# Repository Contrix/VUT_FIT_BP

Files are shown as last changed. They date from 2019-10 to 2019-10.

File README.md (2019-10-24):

# Bakalářská práce
### Vestavěný systém pro monitorování výšky vodní hladiny

Autor práce: Jiří Hanák\
Ak. rok: 2018/2019\
Vedoucí: Ing. Václav Šimek\
Oponent: Ing. Tomáš Kašpárek\
Publikace na webu školy: https://www.vutbr.cz/studenti/zav-prace/detail/122051

##### Abstrakt 
Tato práce se zabývá návrhem a realizací vestavěného systému pro monitorování výšky vodní hladiny. Účelem systému je řízení napouštění nádrže na základě výšky vodní hladiny. V první řadě je věnována pozornost přehledu stávajících měřicích technik a výběru vhodných měřicích prvků pro daný scénář. Vestavěný systém staví na bezkontaktních snímačích TFmini a JSN-SR04T-2.0. Řízení systému obstarává mikrokontrolér řady STM32F0 od firmy STMicroelectronics programovaný v jazyce C s využitím abstraktní vrstvy HAL. Naměřené výsledky jsou odesílány přes Wi-Fi SoC ESP8266EX na demonstrační server v jazyce Python.

##### Klíčová slova
Vestavěný systém, měření vzdálenosti, STM32, návrh DPS, nádrž, voda, ESP8266, ČSN EN 60 529, HAL

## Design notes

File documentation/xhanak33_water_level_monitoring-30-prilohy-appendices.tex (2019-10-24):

\chapter{Finální podoba vestavěného systému}
    \label{sec:fotky}

    \begin{figure*}[h]
        \centering
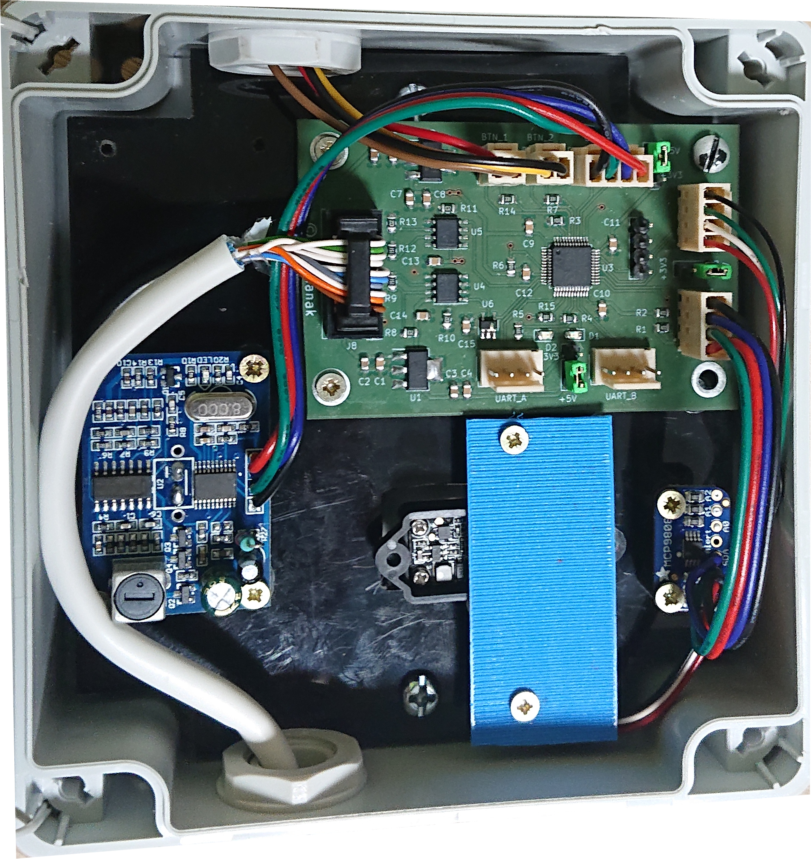
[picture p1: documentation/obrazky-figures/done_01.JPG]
        
        \caption{Pohled na otevřenou krabici reprezentující řídicí část vestavěného systému.}
    \end{figure*}

    \begin{figure*}[h]
        \centering
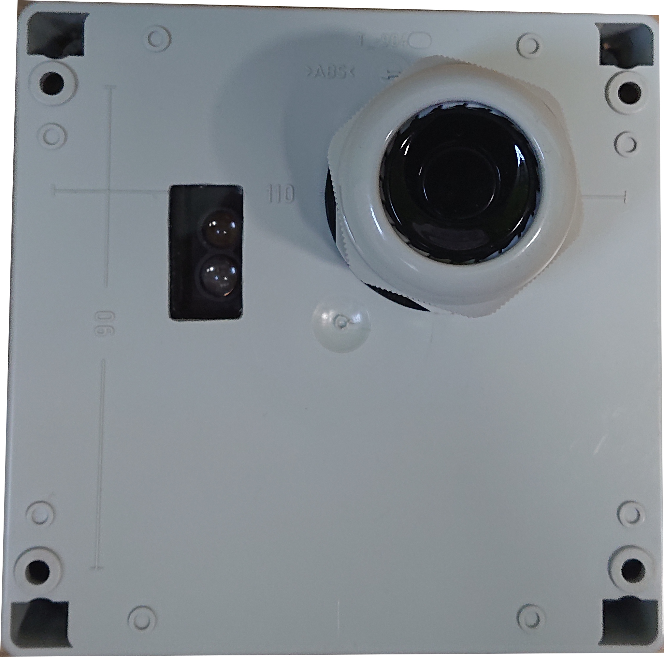
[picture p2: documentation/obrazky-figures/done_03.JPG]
        
        \caption{Pohled na spodní část krabice reprezentující řídicí část vestavěného systému.}
    \end{figure*}

    \begin{figure*}[h]
        \centering
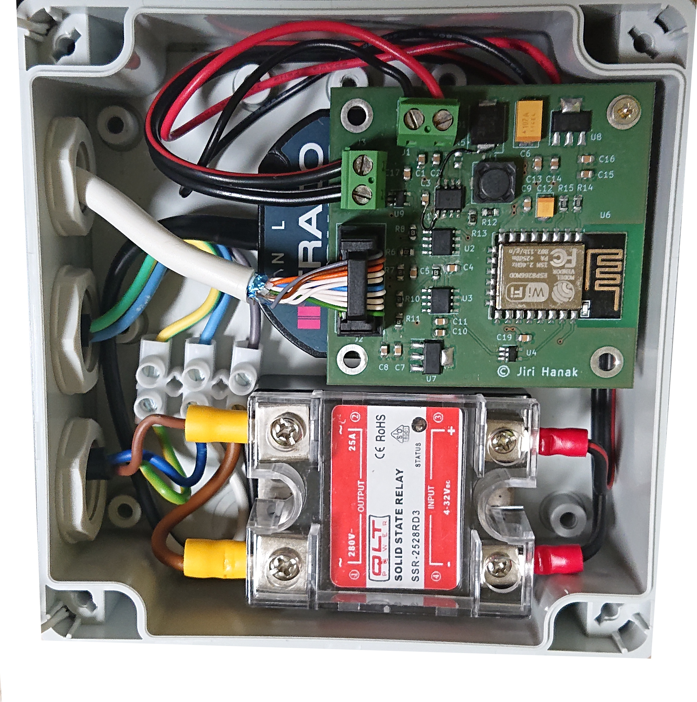
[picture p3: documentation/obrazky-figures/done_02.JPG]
        
        \caption{Pohled na otevřenou krabici reprezentující podpůrnou část vestavěného systému.}
    \end{figure*}
\chapter{Výsledky testovacího měření TFmini a JSN-SR04T-2.0}
	\label{sec:values}
	\begin{table*}[h]\centering
        \begin{tabular}{@{}cccccccc@{}}
            \toprule
            \multirow{2}{*}{\textbf{Reference}} & \multicolumn{3}{c}{\textbf{TFmini}} && \multicolumn{3}{c}{\textbf{JSN-SR04T-2.0}}\\ 
            \cmidrule{2-4}\cmidrule{6-8}
            	& \textbf{Podlaha}    & \textbf{Voda}      & \textbf{Pěna}&& \textbf{Podlaha}    & \textbf{Voda}      & \textbf{Pěna}\\
            \midrule
            400		& 372	& 988	& 470	&& 398	& 353	& 357	\\ 
            500		& 486	& 1040	& 589	&& 506	& 448	& 452	\\ 
            600		& 590	& 1087	& 673	&& 601	& 558	& 558	\\ 
            700		& 680	& 1142	& 744	&& 691	& 644	& 665	\\ 
            800		& 782	& 1155	& 816	&& 795	& 750	& 756	\\ 
            900		& 872	& 1169	& 905	&& 896	& 853	& 853	\\ 
            1000	& 995	& 1212	& 1009	&& 1002	& 941	& 982	\\ 
            1100	& 1092	& 1240	& 1087	&& 1096	& 1047	& 1073	\\
            1200	& 1185	& 1255	& 1182	&& 1198	& 1183	& 1157	\\ 
            1300	& 1280	& 1321	& 1275	&& 1301	& 1247	& 1252	\\ 
            1400	& 1381	& 1408	& 1379	&& 1394	& 1355	& 1370	\\ 
            1500	& 1486	& 1511	& 1462	&& 1487	& 1459	& 1510	\\ 
            1600	& 1584	& 1631	& 1547	&& 1590	& 1592	& 1558	\\ 
            1700	& 1672	& 1718	& 1657	&& 1693	& 1655	& 1663	\\ 
            1800	& 1786	& 1790	& 1750	&& 1792	& 1741	& 1754	\\ 
            1900	& 1875	& 1899	& 1878	&& 1900	& 1853	& 1853	\\ 
            2000	& 1995	& 1998	& 1953	&& 1989	& 1976	& 1948	\\ 
            \bottomrule
        \end{tabular}
        \caption{V~tabulce jsou uvedeny změřené hodnoty optickým snímačem \io{TFmini} a ultrazvukovým snímačem \io{JSN-SR04T-2.0} kolmo proti podlaze, klidné vodní hladině a zpěněné hladině vody při teplotě $20\unit{^\circ C}$. Všechny hodnoty jsou uvedeny v~milimetrech.}
    \end{table*}

\chapter{Ukázka konfiguračního souboru}
	\label{sec:cfg}
	\begin{lstlisting}
    # datum zmeny pro 23.3. 2018, verze 2
CHANGE_ID=2018032302
    # pocet minut do opetovneho nacteni konfigurace a odeslani namerenych dat
REFRESH=1440
    # adresa severu
SERVER="muj_server.cz/"
    # umisteni obsluzneho skriptu na serveru
LOCATION="water_level_monitoring"
    # port skriptu
PORT=5000
    # wifi sit 
SSID="moje_sit"
    # heslo na wifi
PASSWORD="heslo_na_wifi"
    # vyska nadrze v milimetrech
HEIGHT=2000
    # maximalni vyska hladiny v milimetrech
MAXUMUM=1800
    # minimalni vyska hladiny v milimetrech
MINIMUM=50
    # ovladani cerpadla v rezimu napousteni
PUMP_ACTIVE=1
    # pocet mereni na vyhodnoceni vysky vodni hladiny
AVERAGE_COUNT=5
    # soucet identifikatoru aktivnich senzoru
CONTROL_SENSORS=15\end{lstlisting}

\chapter{Ukázka konfigurace přes rozhraní UART}
    \label{sec:cfg}
    \begin{lstlisting}
Odposlech
cu -l /dev/ttyUSB0 -s 9600

Zapis
Inicializace
echo -ne '5000\r\n' > /dev/ttyUSB0
echo -ne '"10.42.0.1"\r\n' > /dev/ttyUSB0

Zmena konfigurace
echo -ne '\x07' > /dev/ttyUSB0
echo -ne 'REFRESH=1\r\n' > /dev/ttyUSB0
echo -ne 'SERVER="10.42.0.1"\r\n' > /dev/ttyUSB0
echo -ne 'LOCATION="water_level_mnt"\r\n' > /dev/ttyUSB0
echo -ne '\x06' > /dev/ttyUSB0

Programovani
STM32_Programmer_CLI -c port=SWD reset=HWrst -w main.bin 0x08000000 -v -rst

Uplna ukazkova inicializace
echo -ne '1\r\n' > /dev/ttyUSB0
echo -ne '"10.42.0.1"\r\n' > /dev/ttyUSB0
echo -ne '"water_level_monitoring"\r\n' > /dev/ttyUSB0
echo -ne '5000\r\n' > /dev/ttyUSB0
echo -ne '"Wifi"\r\n' > /dev/ttyUSB0
echo -ne '"heslo"\r\n' > /dev/ttyUSB0
echo -ne '5000\r\n' > /dev/ttyUSB0
echo -ne '2000\r\n' > /dev/ttyUSB0
echo -ne '200\r\n' > /dev/ttyUSB0
echo -ne '1\r\n' > /dev/ttyUSB0
echo -ne '3\r\n' > /dev/ttyUSB0
echo -ne '15\r\n' > /dev/ttyUSB0\end{lstlisting}

\chapter{Schéma řídicí desky}
	\label{sec:main_board_scheme}
	\includepdf[landscape=true, offset=20 -40]{obrazky-figures/main_board_scheme.pdf}

\chapter{Plošný spoj pro řídicí desku}
	\label{sec:main_board_pcb}
    \includepdf[pages={1,2}, landscape=true, angle=270, offset=20 -40]{obrazky-figures/main_board_pcb.pdf}

\chapter{Schéma podpůrné desky}
	\label{sec:support_board_scheme}
	\includepdf[landscape=true, offset=20 -40]{obrazky-figures/support_board_scheme.pdf}

\chapter{Plošný spoj pro podpůrnou desku}
	\label{sec:support_board_pcb}
	\includepdf[pages={1,2}, landscape=true, offset=20 -40]{obrazky-figures/support_board_pcb.pdf}

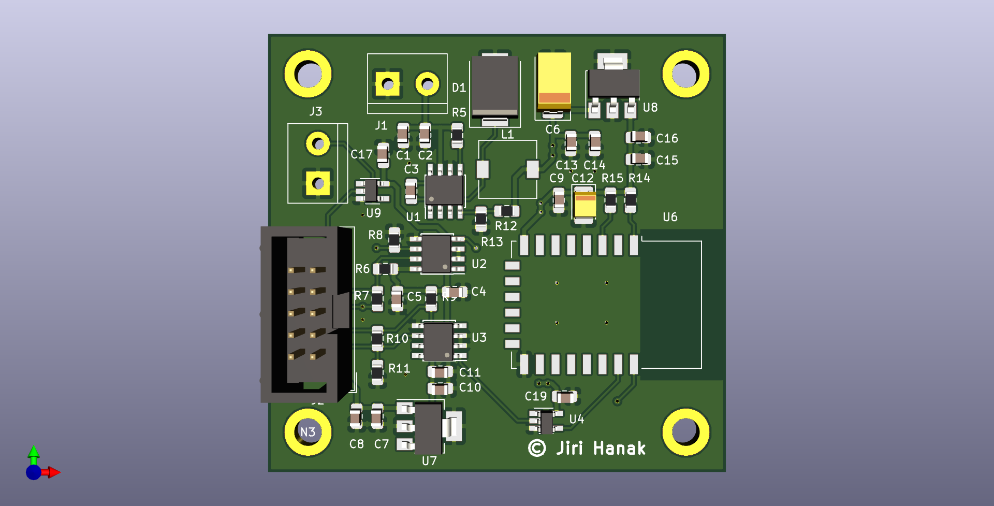
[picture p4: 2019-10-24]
documentation/obrazky-figures/support_board_3D.png

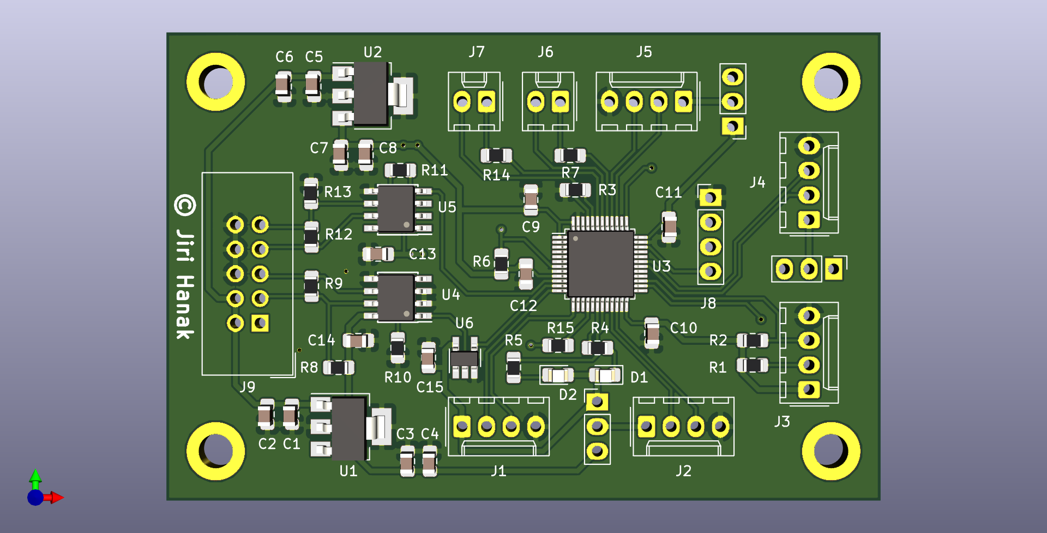
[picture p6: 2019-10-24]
documentation/obrazky-figures/main_board_3D.png

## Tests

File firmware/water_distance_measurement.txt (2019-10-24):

Configuration	water_distance_measurement
STM32CubeMX 	4.27.0
Date	05/14/2019
MCU	STM32F030CCTx

PERIPHERALS	MODES	FUNCTIONS	PINS
I2C2	I2C	I2C2_SCL	PB13
I2C2	I2C	I2C2_SDA	PB14
SYS	Serial_Wire	SYS_SWCLK	PA14
SYS	Serial_Wire	SYS_SWDIO	PA13
SYS	SysTick	SYS_VS_Systick	VP_SYS_VS_Systick
USART1	Asynchronous	USART1_RX	PA10
USART1	Asynchronous	USART1_TX	PA9
USART2	Asynchronous	USART2_RX	PA3
USART2	Asynchronous	USART2_TX	PA2
USART3	Asynchronous	USART3_RX	PB11
USART3	Asynchronous	USART3_TX	PB10
USART4	Asynchronous	USART4_RX	PA1
USART4	Asynchronous	USART4_TX	PA0
USART5	Asynchronous	USART5_RX	PB4
USART5	Asynchronous	USART5_TX	PB3

Pin Nb	PINs	FUNCTIONs	LABELs
10	PA0	USART4_TX	
11	PA1	USART4_RX	
12	PA2	USART2_TX	
13	PA3	USART2_RX	
16	PA6	GPIO_Output	SSR
18	PB0	GPIO_Output	LED1
19	PB1	GPIO_Output	LED2
21	PB10	USART3_TX	
22	PB11	USART3_RX	
26	PB13	I2C2_SCL	
27	PB14	I2C2_SDA	
30	PA9	USART1_TX	
31	PA10	USART1_RX	
34	PA13	SYS_SWDIO	
37	PA14	SYS_SWCLK	
39	PB3	USART5_TX	
40	PB4	USART5_RX	
41	PB5	GPIO_Output	Matrix_X1
42	PB6	GPIO_Input	Matrix_Y1
43	PB7	GPIO_Output	Matrix_X2
45	PB8	GPIO_Input	Matrix_Y2

SOFTWARE PROJECT

Project Settings : 
Project Name : water_distance_measurement
Project Folder : /mnt/sda6/fit/bp/bachelors_thesis/firmware
Toolchain / IDE : Makefile
Firmware Package Name and Version : STM32Cube FW_F0 V1.9.0

Code Generation Settings : 
STM32Cube Firmware Library Package : Copy all used libraries into the project folder
Generate peripheral initialization as a pair of '.c/.h' files per peripheral : No
Backup previously generated files when re-generating : No
Delete previously generated files when not re-generated : Yes
Set all free pins as analog (to optimize the power consumption) : Yes

Toolchains Settings : 
Compiler Optimizations :

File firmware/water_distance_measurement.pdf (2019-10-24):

## water_distance_measurement Project Configuration Report

# 1. Description

## 1.1. Project

Project Name | water_distance_measurement
Board Name | custom
Generated with: | STM32CubeMX 4.27.0
Date | 05/14/2019

## 1.2. MCU

MCU Series | STM32F0
MCU Line | STM32F0x0 Value Line
MCU name | STM32F030CCTx
MCU Package | LQFP48
MCU Pin number | 48

# 2. Pinout Configuration

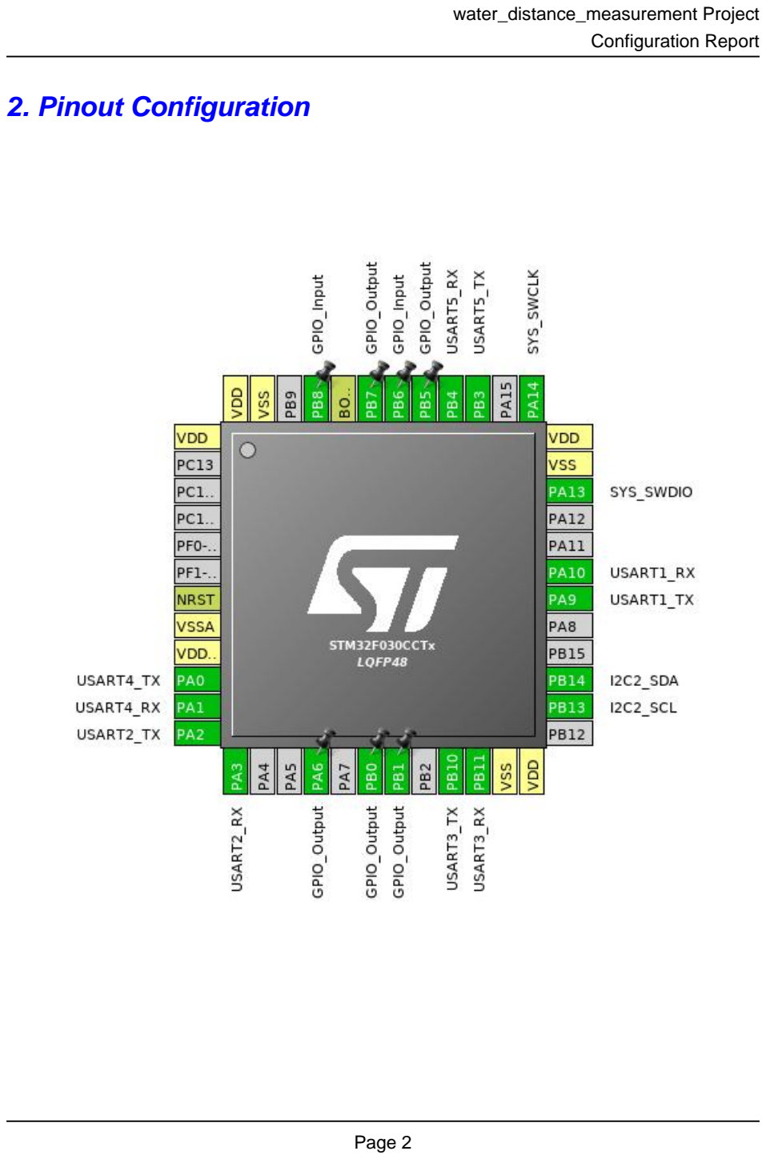
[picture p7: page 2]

# 3. Pins Configuration

Pin Number LQFP48 | Pin Name (function after reset) | Pin Type | Alternate Function(s) | Label
1 | VDD | Power
7 | NRST | Reset
8 | VSSA | Power
9 | VDDA | Power
10 | PA0 | I/O | USART4_TX
11 | PA1 | I/O | USART4_RX
12 | PA2 | I/O | USART2_TX
13 | PA3 | I/O | USART2_RX
16 | PA6 * | I/O | GPIO_Output | SSR
18 | PB0 * | I/O | GPIO_Output | LED1
19 | PB1 * | I/O | GPIO_Output | LED2
21 | PB10 | I/O | USART3_TX
22 | PB11 | I/O | USART3_RX
23 | VSS | Power
24 | VDD | Power
26 | PB13 | I/O | I2C2_SCL
27 | PB14 | I/O | I2C2_SDA
30 | PA9 | I/O | USART1_TX
31 | PA10 | I/O | USART1_RX
34 | PA13 | I/O | SYS_SWDIO
35 | VSS | Power
36 | VDD | Power
37 | PA14 | I/O | SYS_SWCLK
39 | PB3 | I/O | USART5_TX
40 | PB4 | I/O | USART5_RX
41 | PB5 * | I/O | GPIO_Output | Matrix_X1
42 | PB6 * | I/O | GPIO_Input | Matrix_Y1
43 | PB7 * | I/O | GPIO_Output | Matrix_X2
44 | BOOT0 | Boot
45 | PB8 * | I/O | GPIO_Input | Matrix_Y2
47 | VSS | Power
48 | VDD | Power

## * The pin is affected with an I/O function

# 4. Clock Tree Configuration

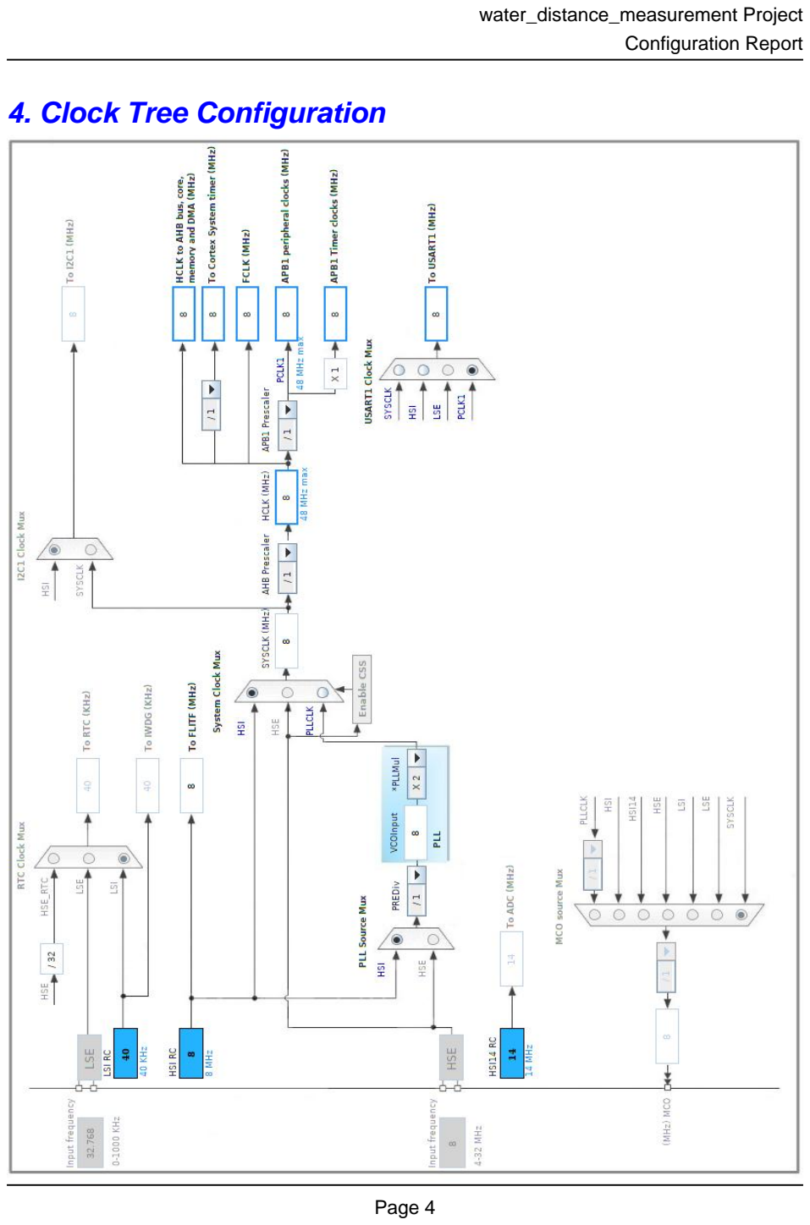
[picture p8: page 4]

# 5. IPs and Middleware Configuration

# 5.1. I2C2

## mode: I2C 5.1.1. Parameter Settings:

### Timing configuration:

I2C Speed Mode | Standard Mode
I2C Speed Frequency (KHz) | 100
Rise Time (ns) | 0
Fall Time (ns) | 0
Coefficient of Digital Filter | 0
Analog Filter | Enabled
Timing | 0x2000090E

### Slave Features:

Clock No Stretch Mode | Disabled
General Call Address Detection | Disabled
Primary Address Length selection | 7-bit
Dual Address Acknowledged | Disabled
Primary slave address | 0

# 5.2. SYS

## mode: Debug Serial Wire Timebase Source: SysTick

# 5.3. USART1

## Mode: Asynchronous 5.3.1. Parameter Settings:

### Basic Parameters:

Baud Rate | 9600 *
Word Length | 8 Bits (including Parity)
Parity | None
Stop Bits | 1

### Advanced Parameters:

Data Direction | Receive and Transmit
Over Sampling | 16 Samples
Single Sample | Disable

### Advanced Features:

Auto Baudrate | Disable
TX Pin Active Level Inversion | Disable
RX Pin Active Level Inversion | Disable
Data Inversion | Disable
TX and RX Pins Swapping | Disable
Overrun | Enable
DMA on RX Error | Enable
MSB First | Disable

# 5.4. USART2

## Mode: Asynchronous 5.4.1. Parameter Settings:

### Basic Parameters:

Baud Rate | 9600 *
Word Length | 8 Bits (including Parity)
Parity | None
Stop Bits | 1

### Advanced Parameters:

Data Direction | Receive and Transmit
Over Sampling | 16 Samples
Single Sample | Disable

### Advanced Features:

Auto Baudrate | Disable
TX Pin Active Level Inversion | Disable
RX Pin Active Level Inversion | Disable
Data Inversion | Disable
TX and RX Pins Swapping | Disable
Overrun | Enable
DMA on RX Error | Enable
MSB First | Disable

# 5.5. USART3

## Mode: Asynchronous 5.5.1. Parameter Settings:

### Basic Parameters:

Baud Rate | 9600 *
Word Length | 8 Bits (including Parity)
Parity | None
Stop Bits | 1

### Advanced Parameters:

Data Direction | Receive and Transmit
Over Sampling | 16 Samples
Single Sample | Disable

### Advanced Features:

Auto Baudrate | Disable
TX Pin Active Level Inversion | Disable
RX Pin Active Level Inversion | Disable
Data Inversion | Disable
TX and RX Pins Swapping | Disable
Overrun | Enable
DMA on RX Error | Enable
MSB First | Disable

# 5.6. USART4

## Mode: Asynchronous 5.6.1. Parameter Settings:

### Basic Parameters:

Baud Rate | 9600 *
Word Length | 8 Bits (including Parity)
Parity | None
Stop Bits | 1

### Advanced Parameters:

Data Direction | Receive and Transmit
Over Sampling | 16 Samples
Single Sample | Disable

### Advanced Features:

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

DMA on RX Error | Enable
MSB First | Disable

# 5.7. USART5

## Mode: Asynchronous 5.7.1. Parameter Settings:

### Basic Parameters:

Baud Rate | 9600 *
Word Length | 8 Bits (including Parity)
Parity | None
Stop Bits | 1

### Advanced Parameters:

Data Direction | Receive and Transmit
Over Sampling | 16 Samples
Single Sample | Disable

### Advanced Features:

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

### * User modified value

# 6. System Configuration

# 6.1. GPIO configuration

IP | Pin | Signal | GPIO mode | GPIO pull/up pull down | Max Speed | User Label
I2C2 | PB13 | I2C2_SCL | Alternate Function Open Drain | No pull-up and no pull-down * | High *
| PB14 | I2C2_SDA | Alternate Function Open Drain | No pull-up and no pull-down * | High *
SYS | PA13 | SYS_SWDIO | n/a | n/a | n/a
| PA14 | SYS_SWCLK | n/a | n/a | n/a
USART1 | PA9 | USART1_TX | Alternate Function Push Pull | No pull-up and no pull-down | High *
| PA10 | USART1_RX | Alternate Function Push Pull | No pull-up and no pull-down | High *
USART2 | PA2 | USART2_TX | Alternate Function Push Pull | No pull-up and no pull-down | High *
| PA3 | USART2_RX | Alternate Function Push Pull | No pull-up and no pull-down | High *
USART3 | PB10 | USART3_TX | Alternate Function Push Pull | No pull-up and no pull-down | High *
| PB11 | USART3_RX | Alternate Function Push Pull | No pull-up and no pull-down | High *
USART4 | PA0 | USART4_TX | Alternate Function Push Pull | No pull-up and no pull-down | High *
| PA1 | USART4_RX | Alternate Function Push Pull | No pull-up and no pull-down | High *
USART5 | PB3 | USART5_TX | Alternate Function Push Pull | No pull-up and no pull-down | High *
| PB4 | USART5_RX | Alternate Function Push Pull | No pull-up and no pull-down | High *
GPIO | PA6 | GPIO_Output | Output Push Pull | No pull-up and no pull-down | Low | SSR
| PB0 | GPIO_Output | Output Push Pull | No pull-up and no pull-down | Low | LED1
| PB1 | GPIO_Output | Output Push Pull | No pull-up and no pull-down | Low | LED2
| PB5 | GPIO_Output | Output Push Pull | No pull-up and no pull-down | Low | Matrix_X1
| PB6 | GPIO_Input | Input mode | Pull-down * | n/a | Matrix_Y1
| PB7 | GPIO_Output | Output Push Pull | No pull-up and no pull-down | Low | Matrix_X2
| PB8 | GPIO_Input | Input mode | Pull-down * | n/a | Matrix_Y2

# 6.2. DMA configuration

## nothing configured in DMA service

# 6.3. NVIC configuration

Interrupt Table | Enable | Preenmption Priority | SubPriority
Non maskable interrupt | true | 0 | 0
Hard fault interrupt | true | 0 | 0
System service call via SWI instruction | true | 0 | 0
Pendable request for system service | true | 0 | 0
System tick timer | true | 0 | 0
Flash global interrupt | true | 0 | 0
I2C2 global interrupt | true | 0 | 0
USART1 global interrupt | true | 0 | 0
USART2 global interrupt | true | 0 | 0
USART3 to USART6 global interrupts | true | 0 | 0
RCC global interrupt | unused

### * User modified value

# 7. Power Consumption Calculator report

### 7.1. Microcontroller Selection

Series | STM32F0
Line | STM32F0x0 Value Line
MCU | STM32F030CCTx
Datasheet | 024849_Rev2

### 7.2. Parameter Selection

Temperature | 25
Vdd | 3.6

# 8. Software Project

## 8.1. Project Settings

Name | Value
Project Name | water_distance_measurement
Project Folder | /mnt/sda6/fit/bp/bachelors_thesis/firmware
Toolchain / IDE | Makefile
Firmware Package Name and Version | STM32Cube FW_F0 V1.9.0

## 8.2. Code Generation Settings

Name | Value
STM32Cube Firmware Library Package | Copy all used libraries into the project folder
Generate peripheral initialization as a pair of '.c/.h' files | No
Backup previously generated files when re-generating | No
Delete previously generated files when not re-generated | Yes
Set all free pins as analog (to optimize the power consumption) | Yes

# 9. Software Pack Report

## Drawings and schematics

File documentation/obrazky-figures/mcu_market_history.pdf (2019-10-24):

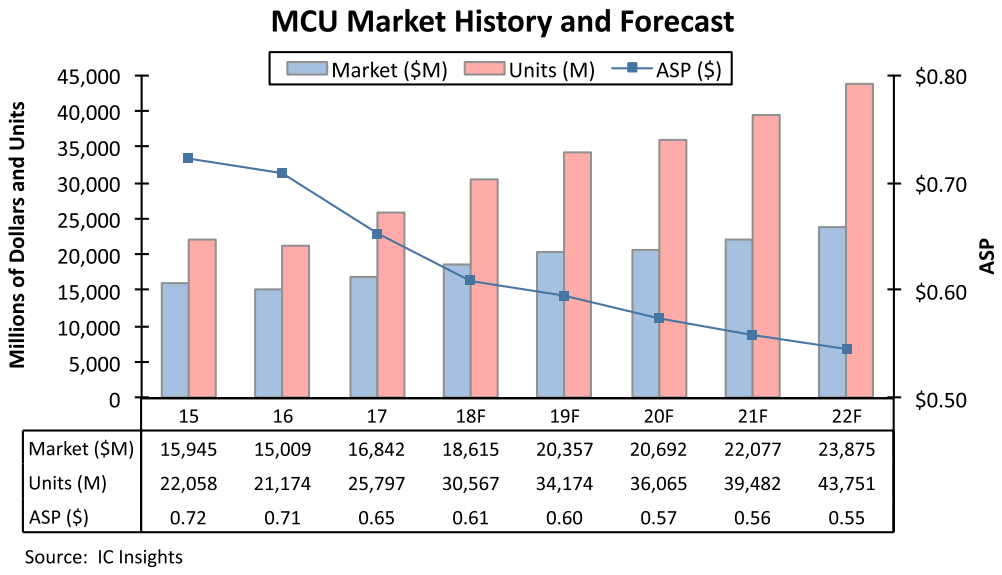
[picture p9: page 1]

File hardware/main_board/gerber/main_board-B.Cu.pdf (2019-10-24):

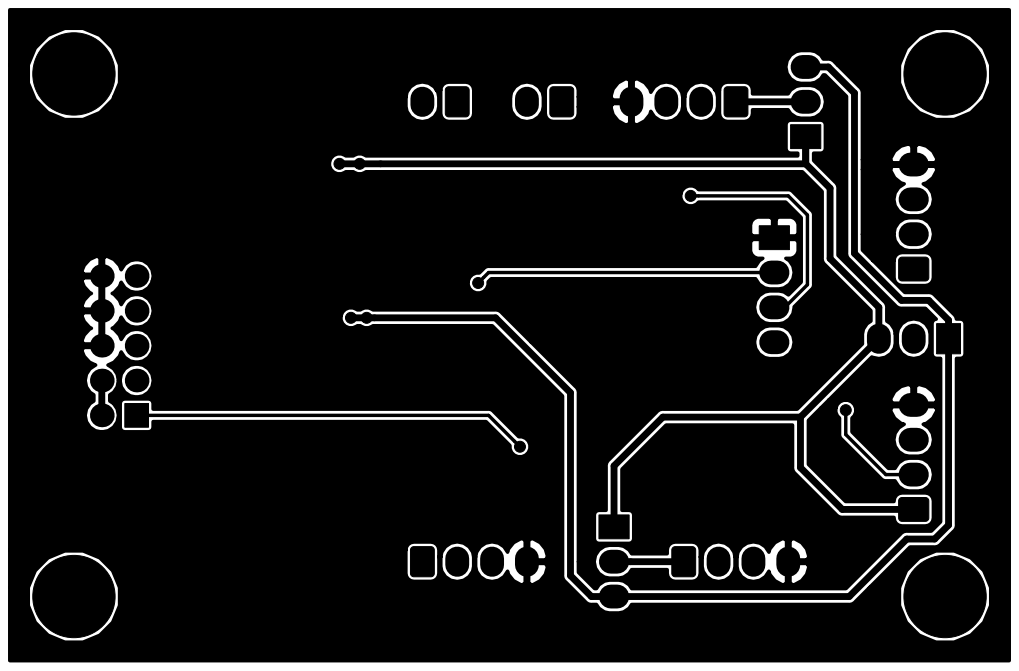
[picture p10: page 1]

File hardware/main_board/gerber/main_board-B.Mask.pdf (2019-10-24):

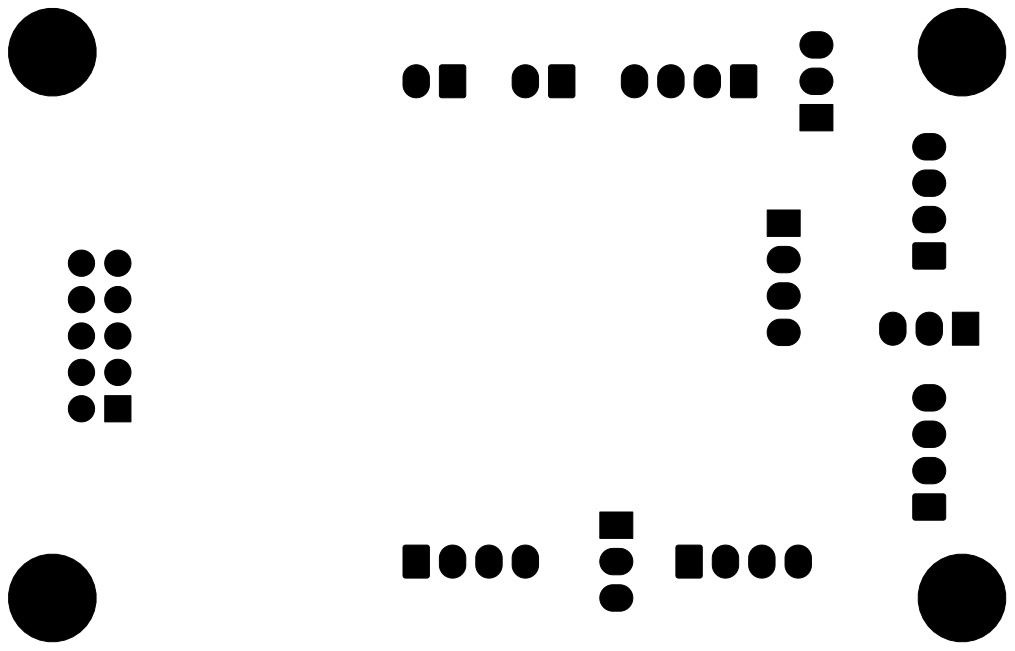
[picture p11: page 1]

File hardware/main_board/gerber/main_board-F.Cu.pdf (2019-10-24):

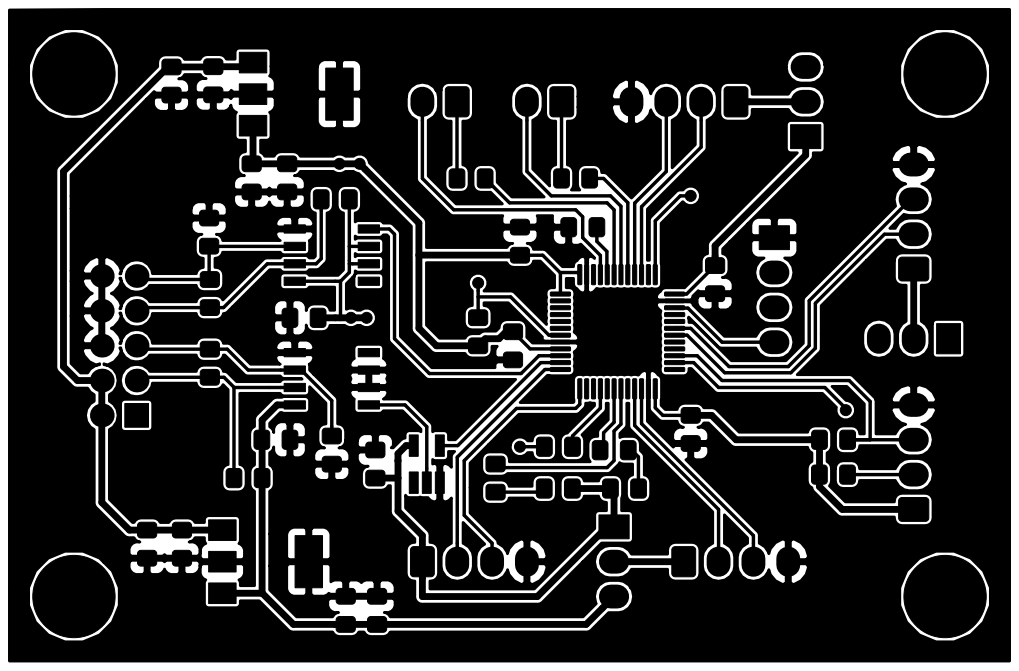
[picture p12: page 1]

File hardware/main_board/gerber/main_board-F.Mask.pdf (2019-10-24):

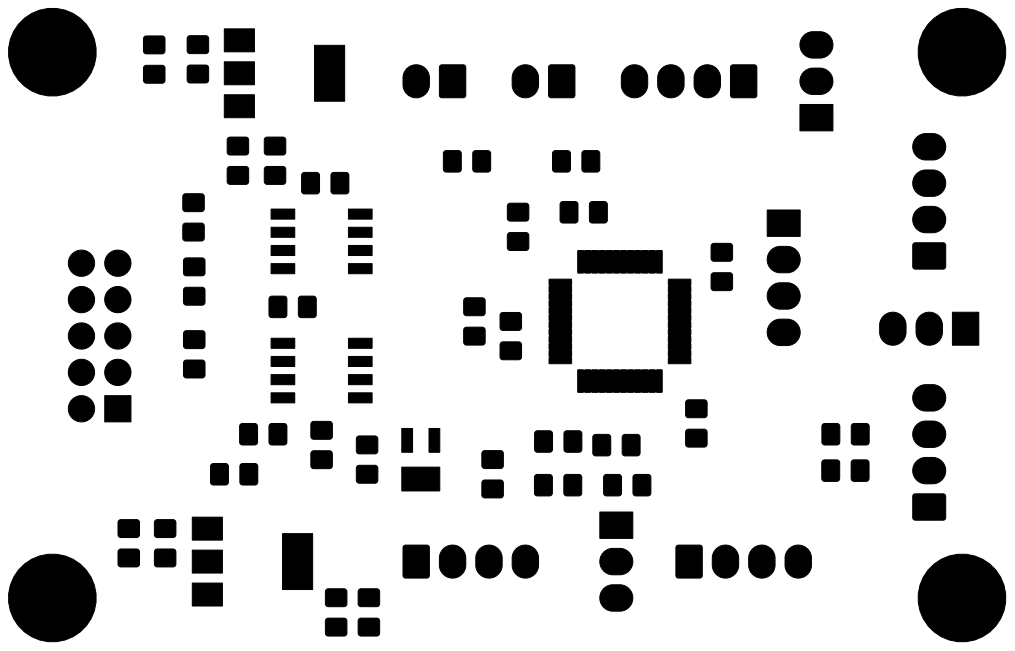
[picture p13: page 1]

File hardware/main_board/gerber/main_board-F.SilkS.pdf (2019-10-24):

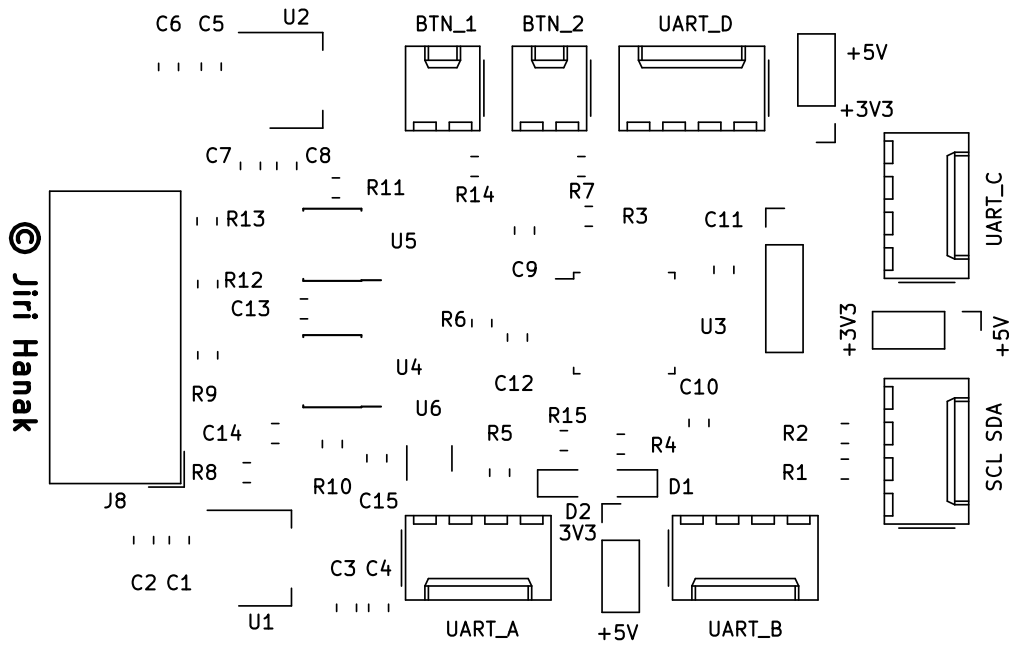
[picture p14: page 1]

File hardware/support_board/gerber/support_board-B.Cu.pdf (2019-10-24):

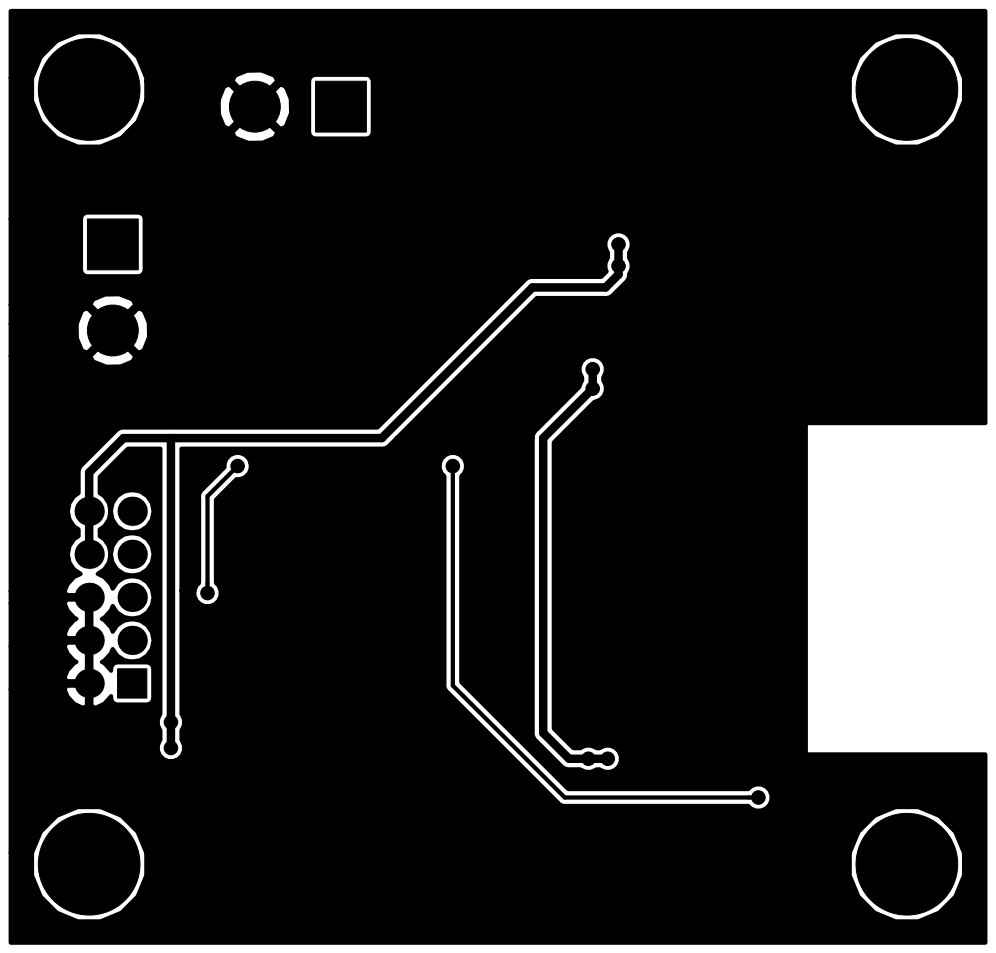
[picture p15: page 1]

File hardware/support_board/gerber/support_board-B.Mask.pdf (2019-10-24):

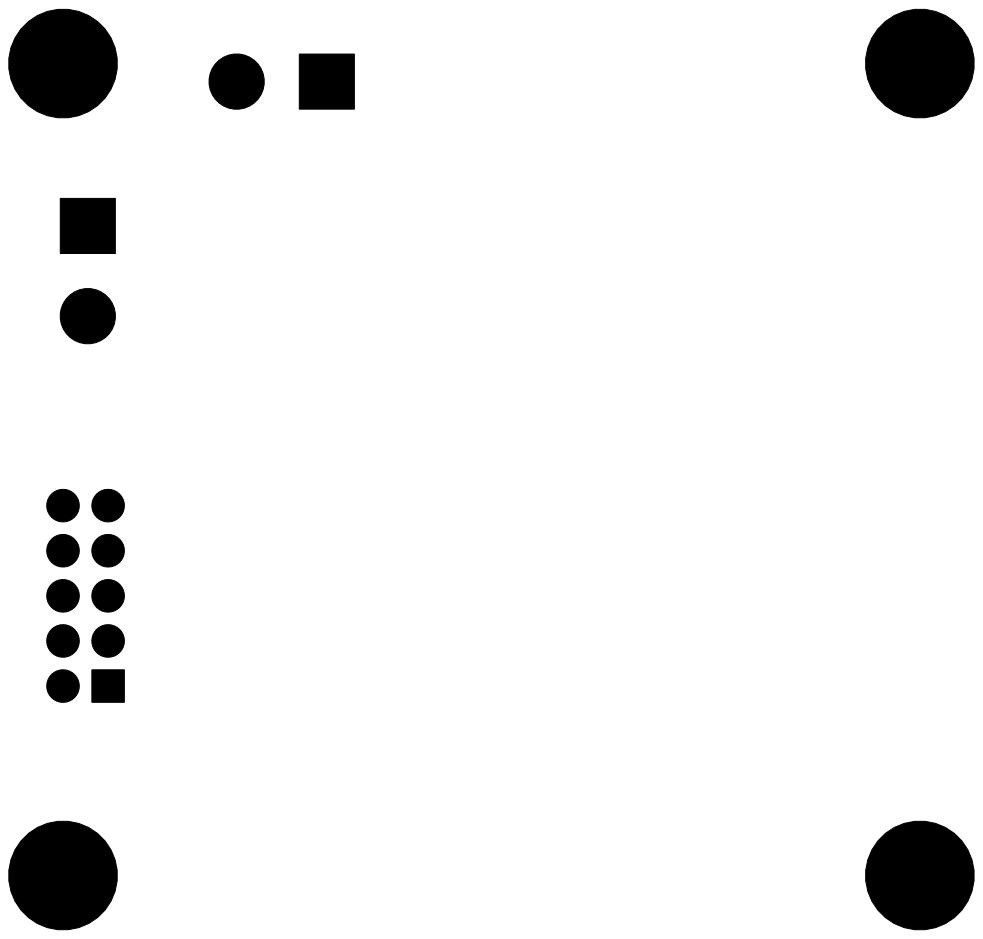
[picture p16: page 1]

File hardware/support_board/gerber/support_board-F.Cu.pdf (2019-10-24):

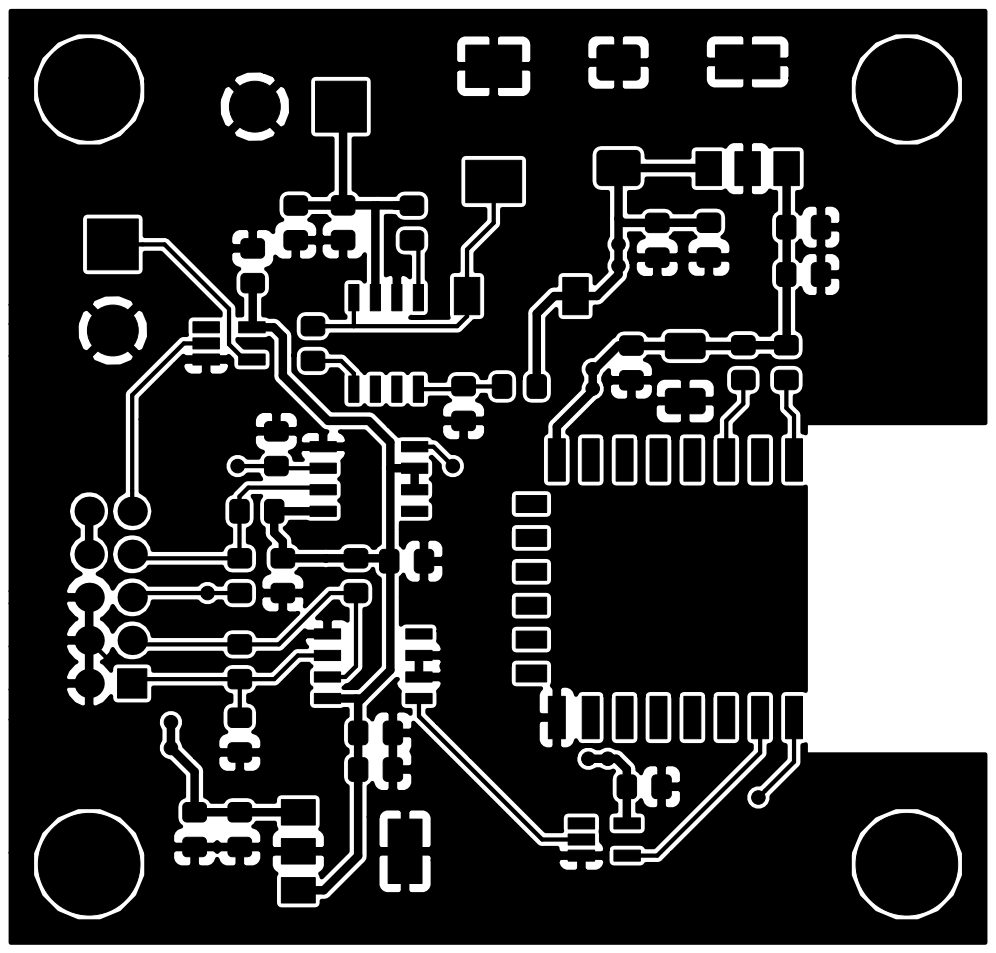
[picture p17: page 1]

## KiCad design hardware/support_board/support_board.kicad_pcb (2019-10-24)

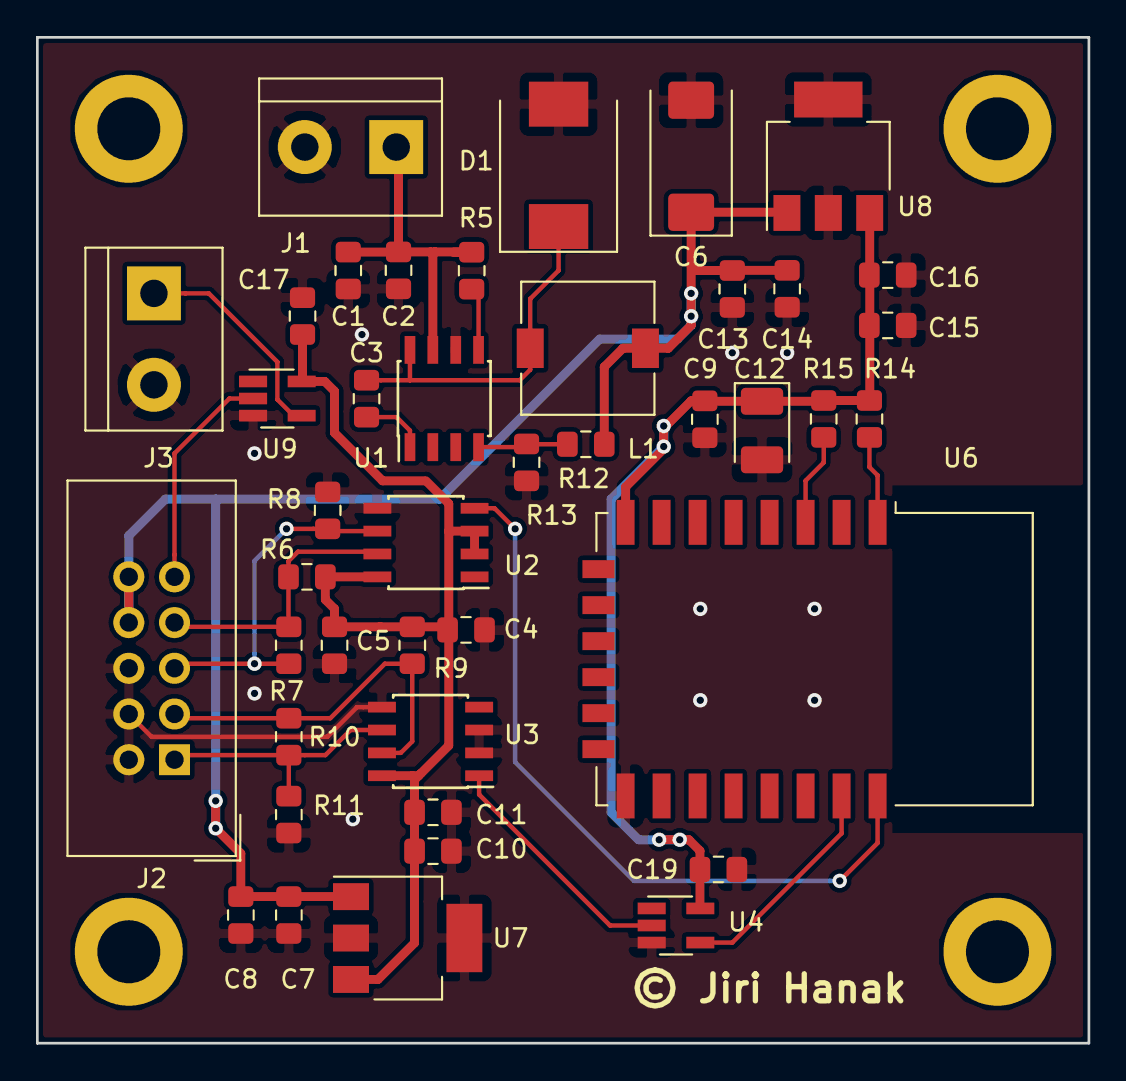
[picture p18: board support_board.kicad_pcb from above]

Board: 2 copper layers, 58.4 x 55.9 mm, 46 parts (0 on the bottom side), 20 nets.

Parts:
C1, C2, C8, C14: 4.7u; C_0805_2012Metric_Pad1.15x1.40mm_HandSolder
C3: 10n; C_0805_2012Metric_Pad1.15x1.40mm_HandSolder
C4, C5, C7, C9, C11, C13, C16, C17, C19: 100n; C_0805_2012Metric_Pad1.15x1.40mm_HandSolder
C6: 100u/10V; CP_EIA-7343-31_Kemet-D
C10, C15: 1u; C_0805_2012Metric_Pad1.15x1.40mm_HandSolder
C12: 22u/10V; CP_EIA-3528-21_Kemet-B_Pad1.50x2.35mm_HandSolder
D1: B340; D_SMC
J1: IN_12V; TerminalBlock_bornier-2_P5.08mm
J2: Main_board; IDC-Header_2x05_P2.54mm_Vertical
J3: SSR_control; TerminalBlock_bornier-2_P5.08mm
L1: 22uH; L_7.3x7.3_H4.5
N1, N2, N3, N4: Screw
R5, R14, R15: 10k; R_0805_2012Metric_Pad1.15x1.40mm_HandSolder
R6, R8, R9, R11: 1k; R_0805_2012Metric_Pad1.15x1.40mm_HandSolder
R7, R10: 150R; R_0805_2012Metric_Pad1.15x1.40mm_HandSolder
R12: 330k; R_0805_2012Metric_Pad1.15x1.40mm_HandSolder
R13: 56k; R_0805_2012Metric_Pad1.15x1.40mm_HandSolder
U1: TPS5420D; SOIC-8_3.9x4.9mm_P1.27mm
U2, U3: SN75LBC176D; SOIC-8_3.9x4.9mm_P1.27mm
U4, U9: SN74LV1T34; SOT-23-5_HandSoldering
U6: ESP-12E
U7: MCP1826S_5V; SOT-223-3_TabPin2
U8: MCP1826S_3.3V; SOT-223-3_TabPin2

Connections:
+3V3: C9.1, C12.1, C15.1, C16.1, C19.2, R14.1, R15.1, U4.5, U6.8, U8.3
+5.5V: C6.1, C7.1, C8.1, C13.1, C14.1, J2.8, J2.10, L1.2, R12.1, U7.1, U8.1
+5V: C4.2, C5.2, C10.1, C11.1, C17.2, R6.1, R9.1, U2.2, U2.3, U2.8, U3.8, U7.3, U9.5
/12V: C1.1, C2.1, J1.1, R5.2, U1.7
GND: C1.2, C2.2, C4.1, C5.1, C6.2, C7.2, C8.2, C9.2, C10.2, C11.2, C12.2, C13.2, C14.2, C15.2, C16.2, C17.1, C19.1, D1.2, J1.2, J2.2, J2.4, J2.6, J3.2, R8.2, R11.2, R13.2, U1.6, U2.5, U3.2, U3.3, U3.5, U4.3, U6.15, U7.2, U8.2, U9.3
unnamed: C3.1, D1.1, L1.1, U1.8
unnamed: C3.2, U1.1
unnamed: J2.1, R10.2, R11.1, U3.6
unnamed: J2.3, R9.2, R10.1, U3.7
unnamed: J2.5, R7.2, R8.1, U2.6
unnamed: J2.7, R6.2, R7.1, U2.7
unnamed: J2.9, U9.2
unnamed: J3.1, U9.4
unnamed: R5.1, U1.5
unnamed: R12.2, R13.1, U1.4
unnamed: R14.2, U6.1
unnamed: R15.2, U6.3
unnamed: U2.4, U6.22
unnamed: U3.1, U4.2
unnamed: U4.4, U6.21

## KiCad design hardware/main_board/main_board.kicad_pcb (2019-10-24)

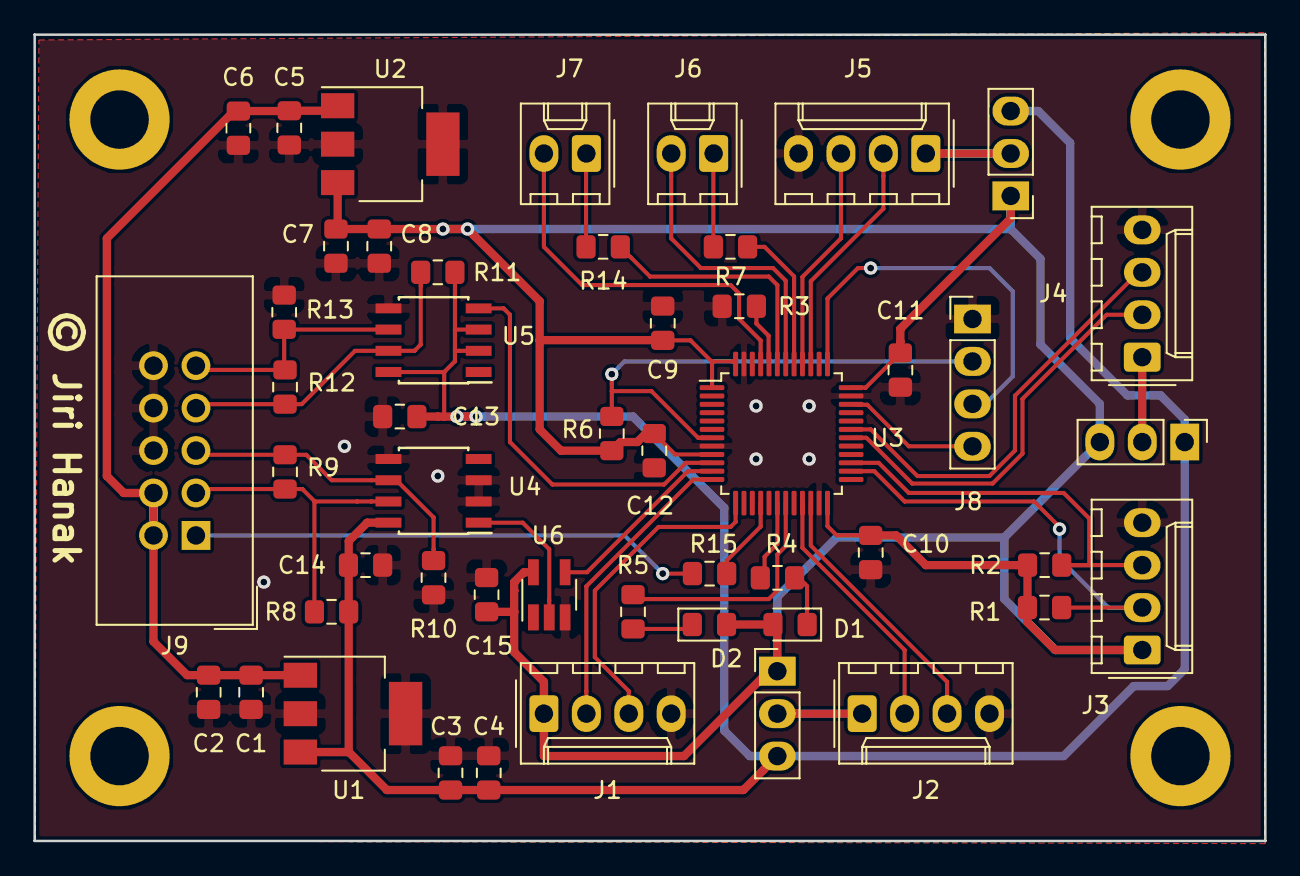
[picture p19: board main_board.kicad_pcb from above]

Board: 2 copper layers, 73.7 x 48.3 mm, 54 parts (0 on the bottom side), 40 nets.

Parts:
C1, C4, C5, C8, C9, C10, C11, C12, C13, C14, C15: 100n; C_0805_2012Metric_Pad1.15x1.40mm_HandSolder
C2, C6: 4.7u; C_0805_2012Metric_Pad1.15x1.40mm_HandSolder
C3, C7: 1u; C_0805_2012Metric_Pad1.15x1.40mm_HandSolder
D1, D2: LED; LED_0805_2012Metric_Pad1.15x1.40mm_HandSolder
J1: UART2; Molex_KK-254_AE-6410-04A_1x04_P2.54mm_Vertical
J2: UART3; Molex_KK-254_AE-6410-04A_1x04_P2.54mm_Vertical
J3: I2C; Molex_KK-254_AE-6410-04A_1x04_P2.54mm_Vertical
J4: UART1; Molex_KK-254_AE-6410-04A_1x04_P2.54mm_Vertical
J5: UART5; Molex_KK-254_AE-6410-04A_1x04_P2.54mm_Vertical
J6: BTN_X; Molex_KK-254_AE-6410-02A_1x02_P2.54mm_Vertical
J7: BTN_Y; Molex_KK-254_AE-6410-02A_1x02_P2.54mm_Vertical
J8: prg_conn; PinHeader_1x04_P2.54mm_Vertical
J9: Support_board; IDC-Header_2x05_P2.54mm_Vertical
N1, N2, N3, N4: Screw
R1, R2: 4k7; R_0805_2012Metric_Pad1.15x1.40mm_HandSolder
R3, R6: 10k; R_0805_2012Metric_Pad1.15x1.40mm_HandSolder
R4, R5, R7, R14, R15: 330R; R_0805_2012Metric_Pad1.15x1.40mm_HandSolder
R8, R10, R11, R13: 1k; R_0805_2012Metric_Pad1.15x1.40mm_HandSolder
R9, R12: 150R; R_0805_2012Metric_Pad1.15x1.40mm_HandSolder
SW1: SW_UART3; PinHeader_1x03_P2.54mm_Vertical
SW2: SW_UART5; PinHeader_1x03_P2.54mm_Vertical
SW5: SW_UART1; PinHeader_1x03_P2.54mm_Vertical
U1: MCP1826S_5V; SOT-223-3_TabPin2
U2: MCP1826S_3.3V; SOT-223-3_TabPin2
U3: STM32F030CCTx; LQFP-48_7x7mm_P0.5mm
U4, U5: SN75LBC176D; SOIC-8_3.9x4.9mm_P1.27mm
U6: SN74LV1T34; SOT-23-5_HandSoldering

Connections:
+3V3: C7.1, C8.1, C9.1, C10.1, C11.1, C12.1, C15.2, D1.2, D2.2, J1.1, J3.1, R1.1, R2.1, R6.1, SW1.1, SW2.1, SW5.3, U2.3, U3.1, U3.9, U3.24, U3.36, U3.48, U6.5
+5.5V: C1.1, C2.1, C5.1, C6.1, J9.2, J9.4, U1.1, U2.1
+5V: C3.1, C4.1, C13.1, C14.1, R8.1, R11.1, SW1.3, SW2.3, SW5.1, U1.3, U4.8, U5.2, U5.3, U5.8
/SCL: J3.2, R1.2, U3.26
/SDA: J3.3, R2.2, U3.27
/SDCLK: J8.3, U3.37
/SDWIO: J8.4, U3.34
/SSR_CONTROL: R15.1, U3.16
/UART1_RX: J4.3, U3.31
/UART1_TX: J4.2, U3.30
/UART2_RX: J1.3, U3.13
/UART2_TX: J1.2, U3.12
/UART3_RX: J2.3, U3.22
/UART3_TX: J2.2, U3.21
/UART4_RX: U3.11, U6.4
/UART4_TX: U3.10, U5.4
/UART5_RX: J5.3, U3.40
/UART5_TX: J5.2, U3.39
/~RST: J8.2, R6.2, U3.7
GND: C1.2, C2.2, C3.2, C4.2, C5.2, C6.2, C7.2, C8.2, C9.2, C10.2, C11.2, C12.2, C13.2, C14.2, C15.1, J1.4, J2.4, J3.4, J4.4, J5.4, J8.1, J9.6, J9.8, J9.10, R3.2, R10.2, R13.2, U1.2, U2.2, U3.8, U3.23, U3.35, U3.47, U4.2, U4.3, U4.5, U5.5, U6.3
unnamed: D1.1, R4.2
unnamed: D2.1, R5.1
unnamed: J2.1, SW1.2
unnamed: J5.1, SW2.2
unnamed: J4.1, SW5.2
unnamed: J6.1, R7.2
unnamed: J6.2, U3.42
unnamed: J9.1, R15.2
unnamed: J9.3, R8.2, R9.1, U4.7
unnamed: J9.5, R9.2, R10.1, U4.6
unnamed: J9.7, R11.2, R12.1, U5.7
unnamed: J9.9, R12.2, R13.1, U5.6
unnamed: J7.1, R14.2
unnamed: J7.2, U3.45
unnamed: R3.1, U3.44
unnamed: R4.1, U3.18
unnamed: R5.2, U3.19
unnamed: R7.1, U3.41
unnamed: R14.1, U3.43
unnamed: U4.1, U6.2

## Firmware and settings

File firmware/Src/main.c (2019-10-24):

/**
  ******************************************************************************
  * @file           : main.c
  * @brief          : Main program body
  ******************************************************************************
  ** This notice applies to any and all portions of this file
  * that are not between comment pairs USER CODE BEGIN and
  * USER CODE END. Other portions of this file, whether 
  * inserted by the user or by software development tools
  * are owned by their respective copyright owners.
  *
  * COPYRIGHT(c) 2019 STMicroelectronics
  *
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
  ******************************************************************************
  */
/* Includes ------------------------------------------------------------------*/
#include "main.h"
#include "stm32f0xx_hal.h"

/* USER CODE BEGIN Includes */

#include "../Drivers/STM32F0xx_HAL_Driver/Inc/stm32f0xx_hal_rcc.h"
#include "../Drivers/STM32F0xx_HAL_Driver/Inc/stm32f0xx_hal_cortex.h"
#include "../Drivers/STM32F0xx_HAL_Driver/Inc/stm32f0xx_hal_flash.h"
#include "../Inc/main.h"
#include "../Drivers/STM32F0xx_HAL_Driver/Inc/stm32f0xx_hal_tim.h"
#include "../Drivers/STM32F0xx_HAL_Driver/Inc/stm32f0xx_hal_pwr.h"


/* USER CODE END Includes */

I2C_HandleTypeDef hi2c2;

UART_HandleTypeDef huart1;
UART_HandleTypeDef huart2;
UART_HandleTypeDef huart3;
UART_HandleTypeDef huart4;
UART_HandleTypeDef huart5;

/* USER CODE BEGIN PV */

/* USER CODE END PV */

void SystemClock_Config(void);
static void MX_GPIO_Init(void);
static void MX_USART1_UART_Init(void);
static void MX_USART2_UART_Init(void);
static void MX_USART3_UART_Init(void);
static void MX_USART4_UART_Init(void);
static void MX_USART5_UART_Init(void);
static void MX_I2C2_Init(void);

/* USER CODE BEGIN PFP */

/* USER CODE END PFP */

/**
  * @brief  The application entry point.
  *
  * @retval None
  */
int main(void)
{
  /* MCU Configuration----------------------------------------------------------*/

  /* Reset of all peripherals, Initializes the Flash interface and the Systick. */
  HAL_Init();

  /* Configure the system clock */
  SystemClock_Config();

  /* Initialize all configured peripherals */
  MX_GPIO_Init();
  MX_USART1_UART_Init();
  MX_USART2_UART_Init();
  MX_USART3_UART_Init();
  MX_USART4_UART_Init();
  MX_USART5_UART_Init();
  MX_I2C2_Init();
  /* USER CODE BEGIN 2 */
  //HAL_TIM_Base_Start_IT(&htim6);
  monitoring_init();
  /* USER CODE END 2 */

  /* Infinite loop */
  /* USER CODE BEGIN WHILE */
  while (1)
  {
    monitoring_loop();

  /* USER CODE END WHILE */

  /* USER CODE BEGIN 3 */

  }
  /* USER CODE END 3 */

}

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


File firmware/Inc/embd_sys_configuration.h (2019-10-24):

/**
 * Water level monitoring
 * Configuration module
 * @Author HanakJiri, xhanak33
 * @file embd_sys_configuration.h
 */

#ifndef WATER_MONITORING_EMBD_SYS_CONFIGURATION_H
#define WATER_MONITORING_EMBD_SYS_CONFIGURATION_H

#include "../Drivers/CMSIS/Device/ST/STM32F0xx/Include/stm32f0xx.h"
#include "../Drivers/CMSIS/Device/ST/STM32F0xx/Include/stm32f030xc.h"
#include "../Drivers/STM32F0xx_HAL_Driver/Inc/stm32f0xx_hal_flash.h"
#include "../Drivers/STM32F0xx_HAL_Driver/Inc/stm32f0xx_hal_flash_ex.h"
#include "../Drivers/STM32F0xx_HAL_Driver/Inc/Legacy/stm32_hal_legacy.h"

#include "../Inc/embd_sys_vector.h"
#include "../Inc/embd_sys_uart.h"

#include <strings.h>
#include <stdlib.h>
#include <stdint-gcc.h>

#define CONFIG_VALUE_LEN 130
#define CONFIG_ID_LEN 24
#define CONNFIG_COUNT 3
#define COMMNET '#'
#define EQ '='

#define CONFIG_CHANGE_ID "CHANGE_ID"
#define CONFIG_REFRESH "REFRESH"
#define CONFIG_SERVER "SERVER"
#define CONFIG_LOCATION "LOCATION"
#define CONFIG_PORT "PORT"
#define CONFIG_MINIMUM "MINIMUM"
#define CONFIG_MAXIMUM "MAXIMUM"
#define CONFIG_HEIGHT "HEIGHT"
#define CONFIG_PUMP_ACTIVE "PUMP_ACTIVE"
#define CONFIG_SSID "SSID"
#define CONFIG_PASSWORD "PASSWORD"
#define CONFIG_CONTROL_SENSORS "CONTROL_SENSORS"
#define CONFIG_AVERAGE "AVERAGE_COUNT"

#define CONFIG_BUFFER_SIZE 160
#define UINT64_MAX_LEN 21

#define CONFIG_LIDAR_ID 1
#define CONFIG_JSN_ID 2
#define CONFIG_FLOATS_ID 4
#define CONFIG_MCP_ID 8

#define CONFIG_FLASH_WORD_LEN 160
#define FLASH_PAGE_ADDRESS 0x803F000U // page 127

typedef enum { STOP_e, FILL_e, DRAIN_e } SSR_state;

typedef struct Configuration_t {
    uint32_t change_id;
    uint32_t refresh;
    uint32_t level_min;
    uint32_t level_max;
    uint32_t height;
    uint8_t pump_active;
    uint8_t control_sensors;
    uint8_t average;
    uint8_t server_address[CONFIG_VALUE_LEN];
    uint16_t server_port;
    uint8_t ssid[CONFIG_VALUE_LEN];
    uint8_t password[CONFIG_VALUE_LEN];
    uint8_t location[CONFIG_VALUE_LEN];
} Configuration_t;

union EMBD_configuration {
    Configuration_t config;
    uint32_t array[CONFIG_FLASH_WORD_LEN];
};

char config_buffer[CONFIG_BUFFER_SIZE];

extern union EMBD_configuration *embd_configuration;
extern void FLASH_PageErase(uint32_t PageAddress);

/**
 *  Initialization of configuration
 */
void init_configuration(union EMBD_configuration *configuration);

/**
 * Reads setting string
 * @param msg Query string
 * @param string Source string
 * @param max Maximal length
 */
void read_string(char *msg, uint8_t *string, uint8_t max);

/**
 * Reads setting number
 * @param msg Query string
 * @param min Minimal value
 * @param max Maximal value
 * @return The number
 */
uint32_t read_number(char *msg, uint32_t min, uint32_t max);

/**
 * Reads word from flash memory
 * @param address
 * @return
 */
uint32_t flash_read(uint32_t address);

/**
 * Reads configuration from flash memory
 * @param configuration Configuration unit
 */
void load_configuration(union EMBD_configuration *configuration);

/**
 * Stores configuration in to flash memory
 */
void store_configuration(union EMBD_configuration *configuration);

/**
 * Sets configuration from string in Vector
 * @param conf Source vector
 * @param force 1 for save by force
 */
void set_configuration(Vector_t *conf, uint8_t force);

/**
 * Sets one setting in configuration
 * @param configuration Destination configuration
 * @param word Key word of setting
 * @param value String to by set
 * @param number Number to by set
 * @return 0 for success
 */
uint8_t set_value(union EMBD_configuration *configuration, char *word, char *value, uint64_t number);

/**
 * Prints all settings
 */
void print_configuration();

/**
 * Skips line in Vector
 * @param conf Source vector
 */
void skip_line(Vector_t *conf);

/**
 * Compare two strings in case insensitivity mode
 * @param id First string
 * @param value Second string
 * @return 1 for same strings
 */
uint8_t string_compare(char* id, char* value);
#endif //WATER_MONITORING_EMBD_SYS_CONFIGURATION_H

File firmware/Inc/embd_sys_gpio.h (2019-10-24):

/**
 * Water level monitoring
 * GPIO module
 * @Author HanakJiri, xhanak33
 * @file embd_sys_gpio.h
 */

#ifndef WATER_MONITORING_EMBD_SYS_GPIO_H
#define WATER_MONITORING_EMBD_SYS_GPIO_H

#include "../Drivers/CMSIS/Device/ST/STM32F0xx/Include/stm32f030xc.h"
#include "../Drivers/STM32F0xx_HAL_Driver/Inc/stm32f0xx_hal.h"
#include "../Drivers/STM32F0xx_HAL_Driver/Inc/stm32f0xx_hal_gpio.h"
#include <stdint-gcc.h>

#define SSR_PIN GPIO_PIN_6
#define SSR_PORT GPIOA

#define LED_1_PIN GPIO_PIN_0
#define LED_2_PIN GPIO_PIN_1
#define LED_PORT GPIOB

#define MATRIX_PIN_X1 GPIO_PIN_5
#define MATRIX_PIN_X2 GPIO_PIN_7
#define MATRIX_PIN_Y1 GPIO_PIN_6
#define MATRIX_PIN_Y2 GPIO_PIN_8
#define MATRIX_PORT GPIOB

#define MATRIX_CONTACT_1 0x01
#define MATRIX_CONTACT_2 0x02
#define MATRIX_CONTACT_3 0x04
#define MATRIX_CONTACT_4 0x08

/**
 * Performs float measurement
 * @return sum of IDs of floats sensors
 */
uint8_t get_matrix();

/**
 * Turn on LED1
 */
void LED1_set();

/**
 * Turn off LED1
 */
void LED1_reset();

/**
 * Toggle LED1
 */
void LED1_toggle();

/**
 * Turn on LED2
 */
void LED2_set();

/**
 * Turn off LED2
 */
void LED2_reset();

/**
 * Toggle LED2
 */
void LED2_toggle();

/**
 * Turn on SSR
 */
void SSR_set();

/**
 * Turn off SSR
 */
void SSR_reset();

#endif //WATER_MONITORING_EMBD_SYS_GPIO_H

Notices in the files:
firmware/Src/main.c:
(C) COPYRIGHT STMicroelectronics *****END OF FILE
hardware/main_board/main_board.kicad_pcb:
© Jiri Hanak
